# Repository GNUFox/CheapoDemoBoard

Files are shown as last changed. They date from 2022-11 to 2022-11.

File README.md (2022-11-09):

# Cheapo Demo Board

This is an attempt at creating a cheap and easy to assemble adapter board for the Raspberry Pi pico (W) to run VGA and PWM-audio demos.

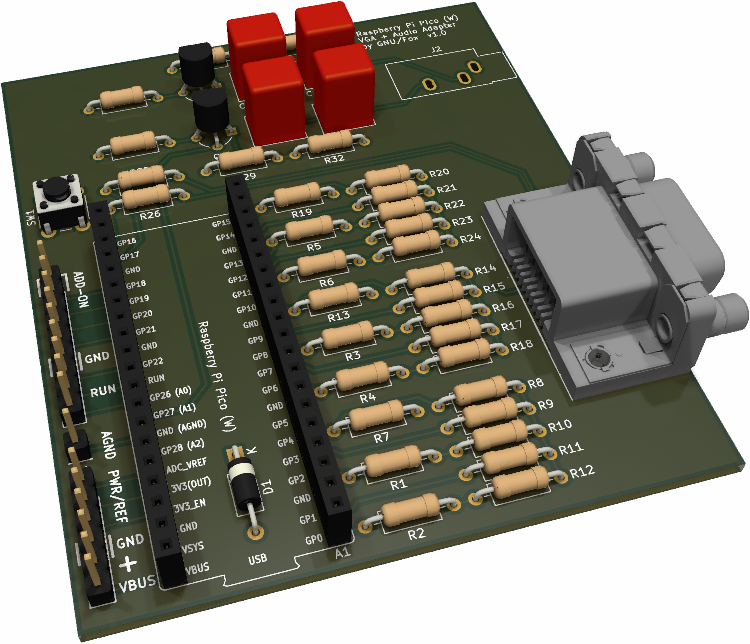
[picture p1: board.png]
THT Board


## Key features
* VGA output via 15-pin SUB-D connector
* Stereo Audio output via 3.5mm jack
* Powered via micro-USB port on pico board or add-on-pin-header
* __Only use two different types of resistors for VGA DAC__
* Easy to assemble THT variant

## TODOs:
 - [ ] Add License
 - [ ] make SMD variant
 - [ ] correct part names in schematic + add BOM

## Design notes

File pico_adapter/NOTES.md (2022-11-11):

https://www.mouser.at/ProductDetail/CUI-Devices/SJ1-3533NG?qs=WyjlAZoYn53GjNky%252BNFGCA%3D%3D

Mouser  636-193-015-213R531 NorComp 193-015-213R531

# Missing VGA connector?
Download from https://www.mouser.at/ProductDetail/Amphenol-FCI/ICD15S13E4GV00LF
-> Mfg. Part Nr.: ICD15S13E4GV00LF 
-> Mouser Part Nr.: 649-ICD15S13E4GV00LF

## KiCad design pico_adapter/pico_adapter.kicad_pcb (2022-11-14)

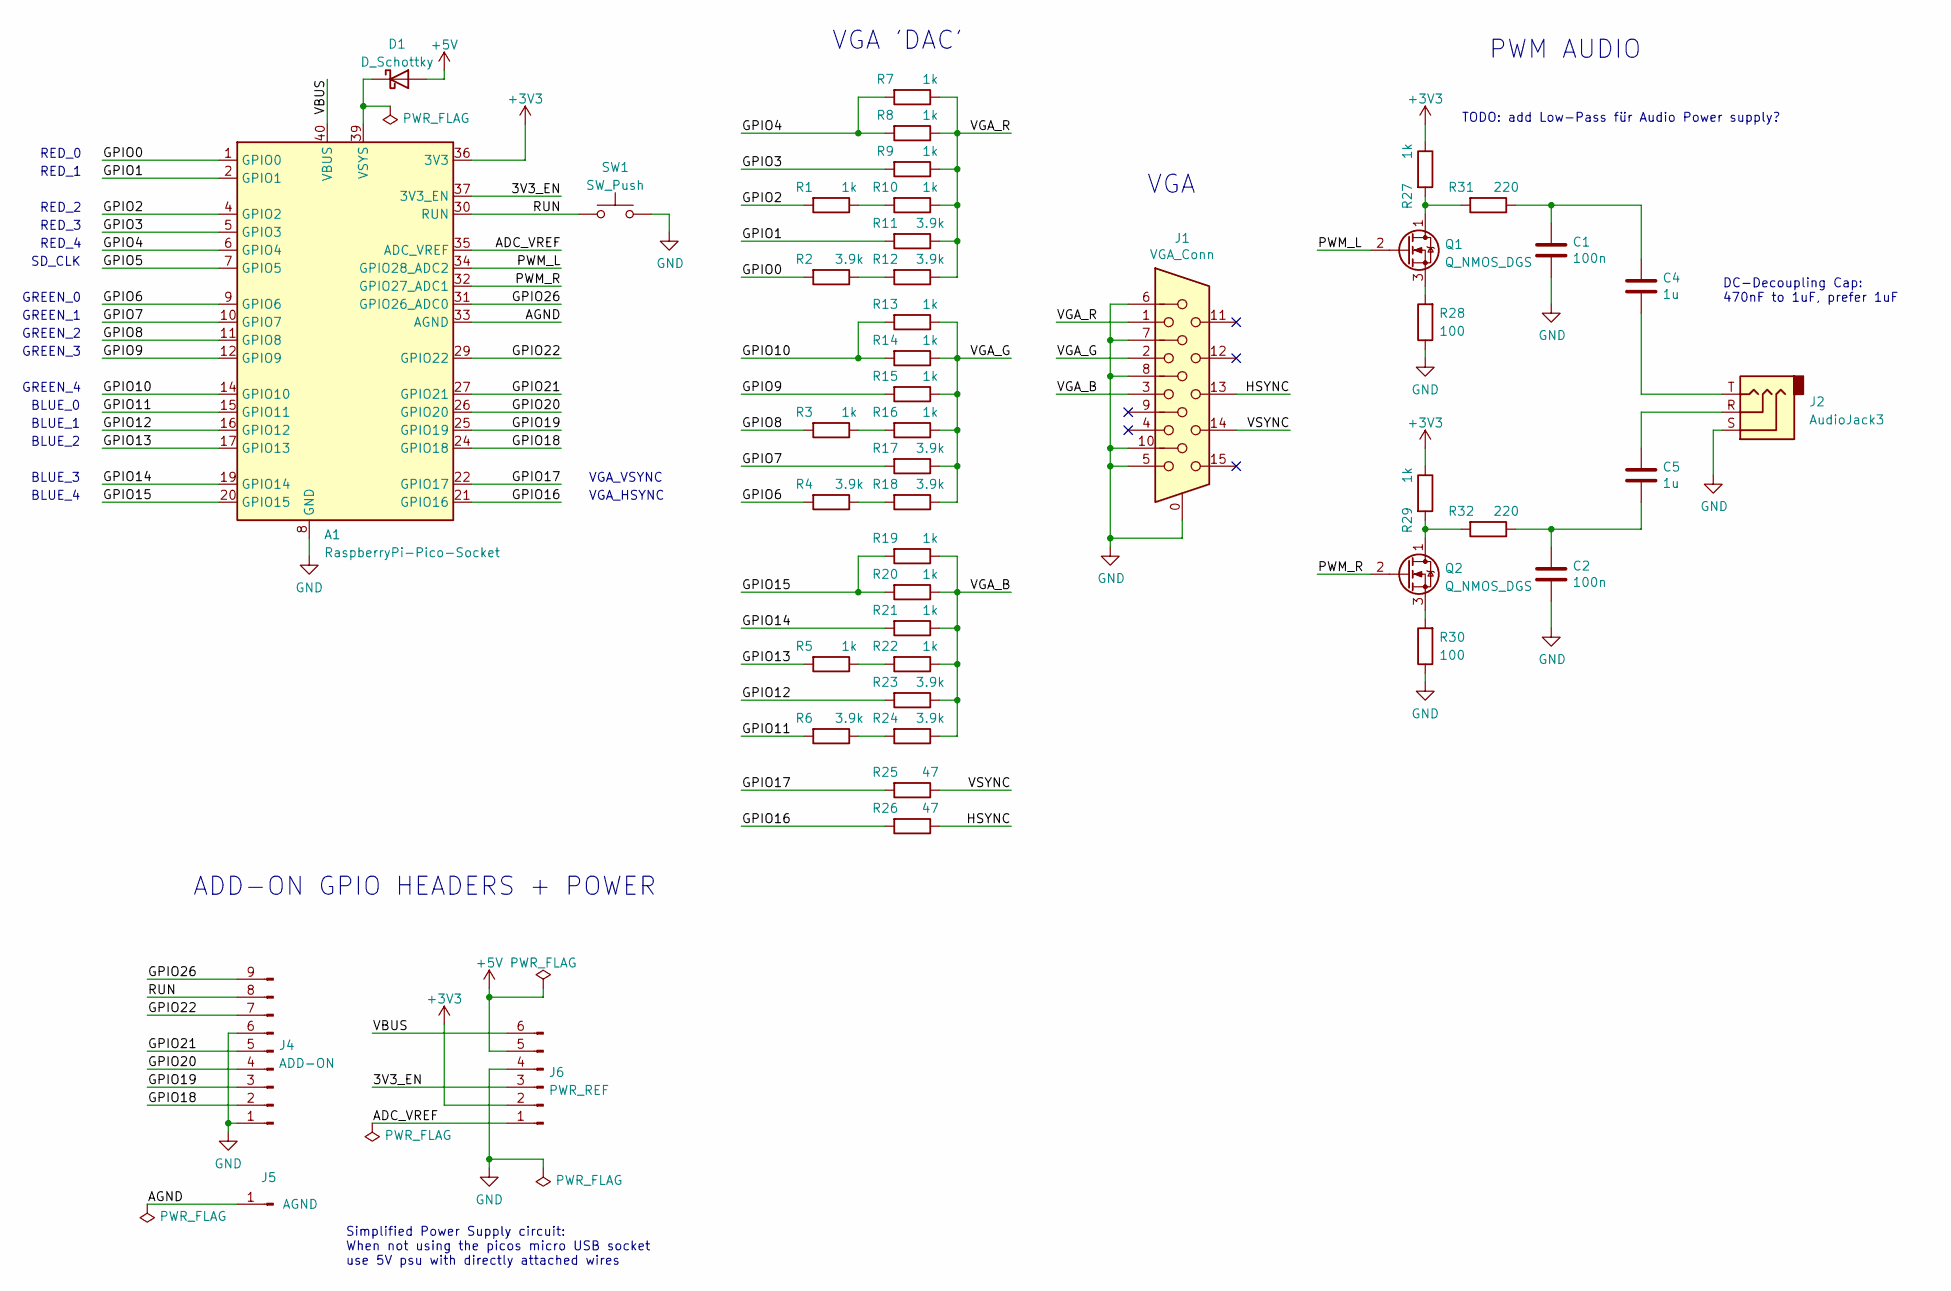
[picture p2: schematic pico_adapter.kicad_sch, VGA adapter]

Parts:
A1: RaspberryPi-Pico-Socket; Raspberry_Pi_Pico_Socket
C1, C2: 100n; C_Rect_L7.5mm_W6.5mm_P5.00mm
C4, C5: 1u; C_Rect_L7.5mm_W6.5mm_P5.00mm
D1: D_Schottky; D_A-405_P10.16mm_Horizontal
J1: VGA_Conn; ICD15S13E4GV00LF
J2: AudioJack3; Jack_3.5mm_CUI_SJ1-3533NG_Horizontal
J4: ADD-ON; PinHeader_1x09_P2.54mm_Vertical
J5: AGND; PinHeader_1x01_P2.54mm_Vertical
J6: PWR_REF; PinHeader_1x06_P2.54mm_Vertical
Q1, Q2: Q_NMOS_DGS; TO-92_Wide
R1, R3, R5, R7, R8, R9, R10, R13, R14, R15, R16, R19, R20, R21, R22, R27, R29: 1k; R_Axial_DIN0207_L6.3mm_D2.5mm_P10.16mm_Horizontal
R2, R4, R6, R11, R12, R17, R18, R23, R24: 3.9k; R_Axial_DIN0207_L6.3mm_D2.5mm_P10.16mm_Horizontal
R25, R26: 47; R_Axial_DIN0207_L6.3mm_D2.5mm_P10.16mm_Horizontal
R28, R30: 100; R_Axial_DIN0207_L6.3mm_D2.5mm_P10.16mm_Horizontal
R31, R32: 220; R_Axial_DIN0207_L6.3mm_D2.5mm_P10.16mm_Horizontal
SW1: SW_Push; SW_PUSH_6mm_H5mm

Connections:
+3V3: A1.36 (3V3), J6.2, R27.1, R29.1
+5V: D1.2 (A), J6.5
/3V3_EN: A1.37 (3V3_EN), J6.3
/ADC_VREF: A1.35 (ADC_VREF), J6.1
/AGND: A1.33 (AGND), J5.1
/GPIO0: A1.1 (GPIO0), R2.2
/GPIO1: A1.2 (GPIO1), R11.2
/GPIO2: A1.4 (GPIO2), R1.2
/GPIO3: A1.5 (GPIO3), R9.2
/GPIO4: A1.6 (GPIO4), R7.2, R8.2
/GPIO5: A1.7 (GPIO5)
/GPIO6: A1.9 (GPIO6), R4.2
/GPIO7: A1.10 (GPIO7), R17.2
/GPIO8: A1.11 (GPIO8), R3.2
/GPIO9: A1.12 (GPIO9), R15.2
/GPIO10: A1.14 (GPIO10), R13.2, R14.2
/GPIO11: A1.15 (GPIO11), R6.2
/GPIO12: A1.16 (GPIO12), R23.2
/GPIO13: A1.17 (GPIO13), R5.2
/GPIO14: A1.19 (GPIO14), R21.2
/GPIO15: A1.20 (GPIO15), R19.2, R20.2
/GPIO16: A1.21 (GPIO16), R26.2
/GPIO17: A1.22 (GPIO17), R25.2
/GPIO18: A1.24 (GPIO18), J4.2
/GPIO19: A1.25 (GPIO19), J4.3
/GPIO20: A1.26 (GPIO20), J4.4
/GPIO21: A1.27 (GPIO21), J4.5
/GPIO22: A1.29 (GPIO22), J4.7
/GPIO26: A1.31 (GPIO26_ADC0), J4.9
/HSYNC: J1.13, R26.1
/PWM_L: A1.34 (GPIO28_ADC2), Q1.2 (G)
/PWM_R: A1.32 (GPIO27_ADC1), Q2.2 (G)
/RUN: A1.30 (RUN), J4.8, SW1.1
/VBUS: A1.40 (VBUS), J6.6
/VGA_B: J1.3, R19.1, R20.1, R21.1, R22.1, R23.1, R24.1
/VGA_G: J1.2, R13.1, R14.1, R15.1, R16.1, R17.1, R18.1
/VGA_R: J1.1, R7.1, R8.1, R9.1, R10.1, R11.1, R12.1
/VSYNC: J1.14, R25.1
GND: A1.3 (GND), A1.8 (GND), A1.13 (GND), A1.18 (GND), A1.23 (GND), A1.28 (GND), A1.38 (GND), C1.2, C2.2, J1.0, J1.5, J1.6, J1.7, J1.8, J1.10, J2.S, J4.1, J4.6, J6.4, R28.1, R30.1, SW1.2
unnamed: A1.39 (VSYS), D1.1 (K)
unnamed: C1.1, C4.1, R31.1
unnamed: C2.1, C5.2, R32.1
unnamed: C4.2, J2.T
unnamed: C5.1, J2.R
unnamed: Q1.1 (D), R27.2, R31.2
unnamed: Q1.3 (S), R28.2
unnamed: Q2.1 (D), R29.2, R32.2
unnamed: Q2.3 (S), R30.2
unnamed: R1.1, R10.2
unnamed: R2.1, R12.2
unnamed: R3.1, R16.2
unnamed: R4.1, R18.2
unnamed: R5.1, R22.2
unnamed: R6.1, R24.2

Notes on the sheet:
DC-Decoupling Cap: 470nF to 1uF, prefer 1uF
VGA_VSYNC
VGA_HSYNC
PWM AUDIO
SD_CLK
RED_2
GREEN_3
RED_4
BLUE_3
GREEN_4
BLUE_4
GREEN_2
GREEN_0
RED_3
VGA 'DAC'
ADD-ON GPIO HEADERS + POWER
Simplified Power Supply circuit: When not using the picos micro USB socket use 5V psu with directly attached wires
GREEN_1
BLUE_2
RED_1
BLUE_1
BLUE_0
RED_0
VGA
TODO: add Low-Pass für Audio Power supply?

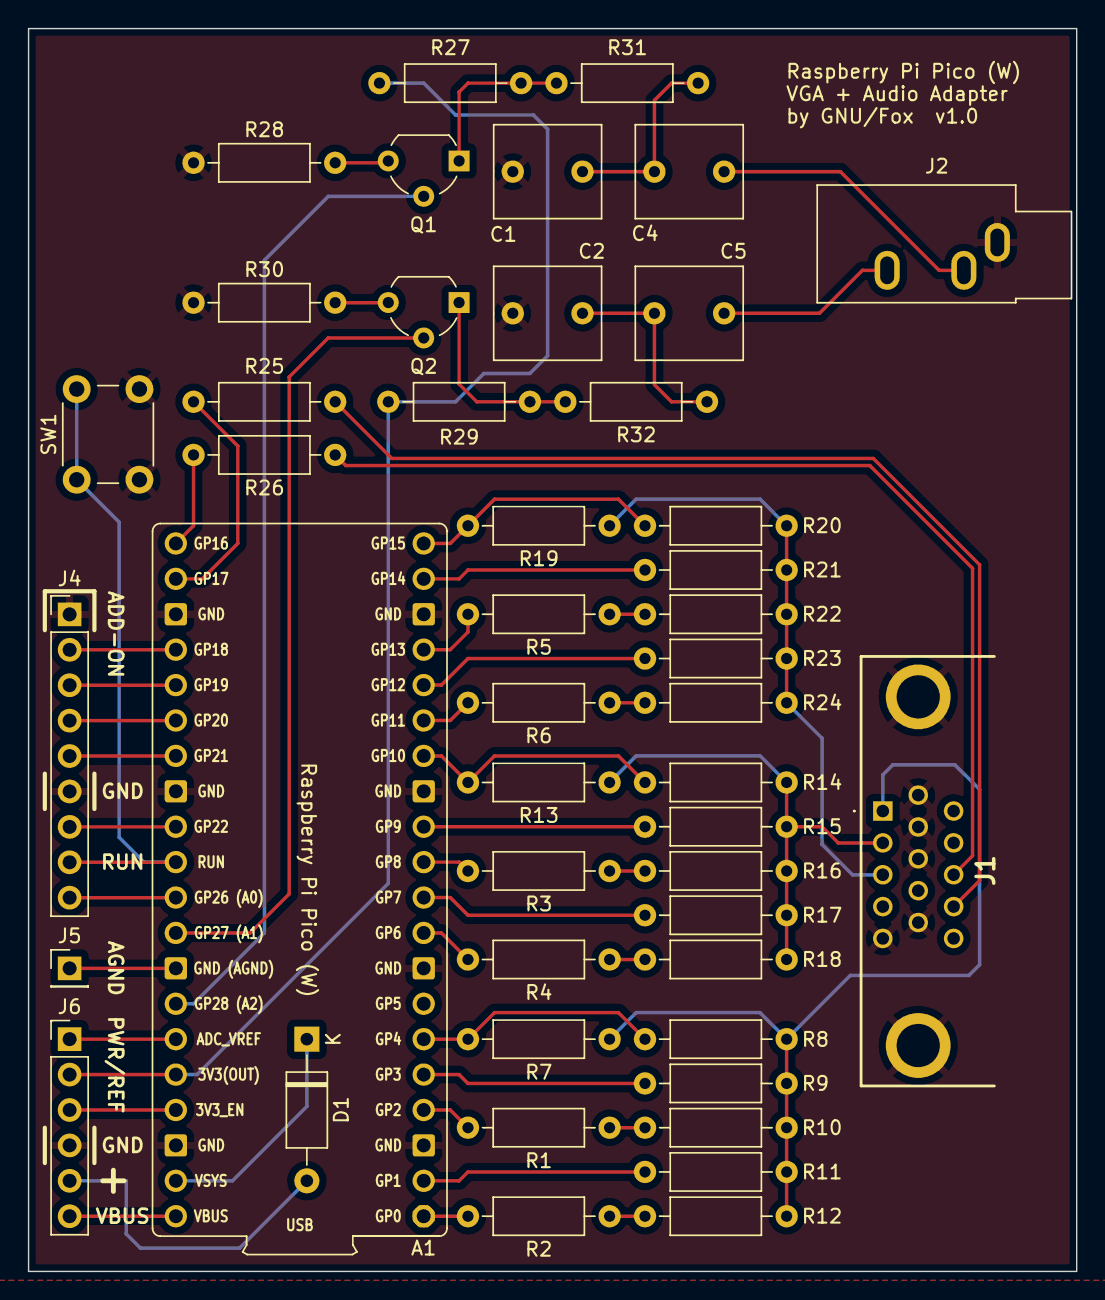
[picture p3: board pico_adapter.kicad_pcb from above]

Board: 2 copper layers, 75.2 x 89.2 mm, 46 parts (0 on the bottom side), 53 nets.

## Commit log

2022-11-08 initial from other repo
    [pico_adapter.kicad_pcb, pico_adapter.kicad_sch]
2022-11-09 minor changes in layout + added image to readme
    [pico_adapter.kicad_pcb]
2022-11-11 changed VGA connector to more widely available variant + adjusted pcb design rules to JLC-PCB values
    [pico_adapter.kicad_pcb, pico_adapter.kicad_sch]
2022-11-11 removed gerber.zip from repo
2022-11-14 cleaned up some traces
    [pico_adapter.kicad_pcb]
